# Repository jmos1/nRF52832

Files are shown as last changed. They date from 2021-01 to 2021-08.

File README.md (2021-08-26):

# nRF52832 Demo Board
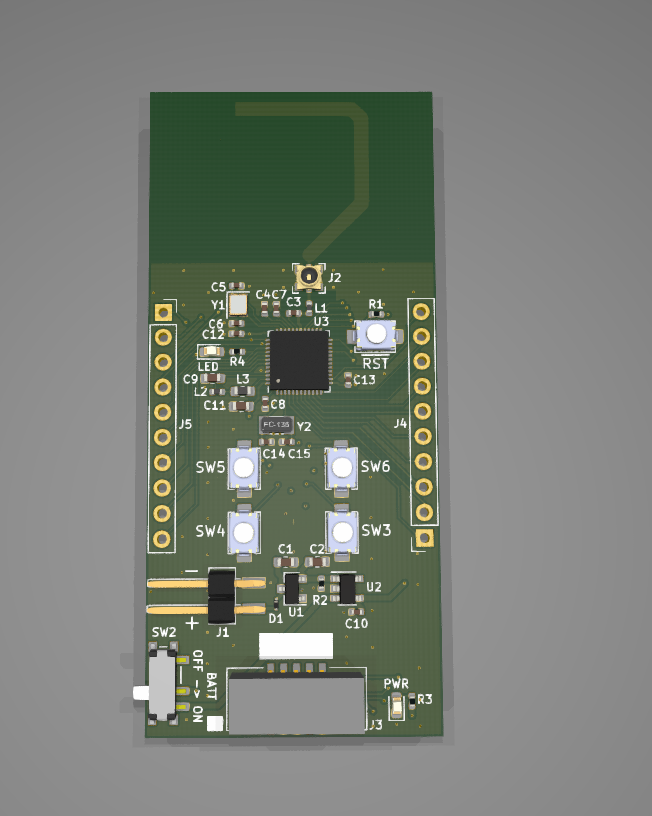
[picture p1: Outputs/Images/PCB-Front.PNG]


### Summary: ###
  4 layer PCB based on Nordic's nRF52832 BLE chip. The antenna needs to be tuned with an exacto knife until
  the VSWR is as close to 1 at 2.4GHz - 2.45GHz as possible. The code to demonstrate that the antenna works 
  as well as the buttons and LEDs will be released when I catch a break from grad school.

  The BOM, schematic PDF, and gerber files are all accessible in the _'Outputs/'_ folder. 
  Other project files are not included because they add clutter and can be generated from the project itself in KiCad.
  Thanks.
  
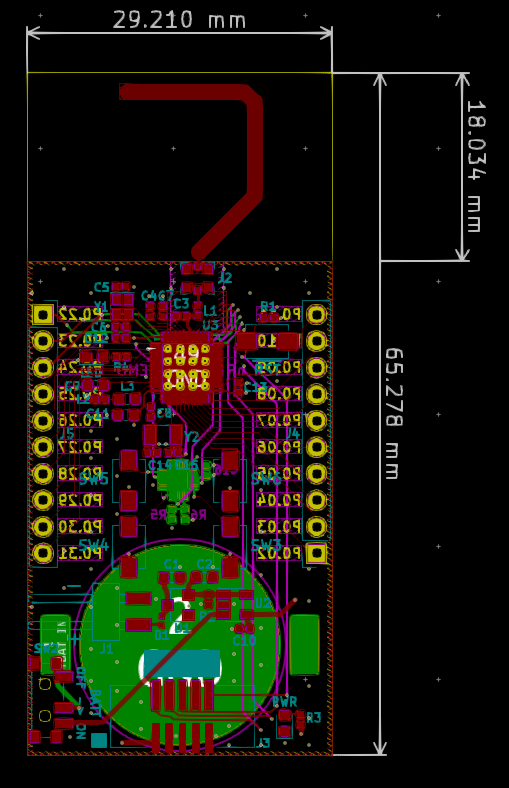
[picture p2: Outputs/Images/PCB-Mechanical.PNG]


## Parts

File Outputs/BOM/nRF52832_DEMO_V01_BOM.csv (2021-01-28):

Reference | Quantity | Value | Description | Manufacturer | MPN | Supplier
BT1 | 1 | CR2032 CLIP | nRF52832_DEMO_V01:BC-2003-G-TR | MPD | BC-2003-G-TR | DigiKey
C11 | 1 | 4u7, 25V | Capacitor_SMD:C_0603_1608Metric | Murata Electronics | GRM188R61E475KE11D | DigiKey
C3 | 1 | 0p8, 100V | Capacitor_SMD:C_0402_1005Metric | Murata Electronics | GRM1555C2AR80BA01D | DigiKey
C4 | 1 | 100p, 25V | Capacitor_SMD:C_0402_1005Metric | Murata Electronics | GRM1555C1E101JA01D | DigiKey
C6 C5 C14 C15 | 4 | 12p, 25V | Capacitor_SMD:C_0402_1005Metric | Murata Electronics | GRM1555C1E120JA01D | DigiKey
C7 | 1 | NC | Capacitor_SMD:C_0402_1005Metric | X | X | DigiKey
C8 C12 C13 C10 C16 | 5 | 100n, 25V | Capacitor_SMD:C_0402_1005Metric | Murata Electronics | GRM155R71E104KE14J | DigiKey
C9 C2 C1 | 3 | 1u, 25V | Capacitor_SMD:C_0603_1608Metric | Murata Electronics | GCM188R71E105KA64D | DigiKey
D1 | 1 | NSR0620P2T5G | nRF52832_DEMO_V01:NSR0620P2T5G | ON Semiconductor | NSR0620P2T5G | DigiKey
D3 D2 | 2 | GRN | LED_SMD:LED_0603_1608Metric | OSRAM Opto Semiconductors Inc. | LG L29K-F2J1-24-Z | DigiKey
J1 | 1 | M20-8890245 | nRF52832_DEMO_V01:M20-8890245 | Harwin Inc. | M20-8890245 | DigiKey
J2 | 1 | MM8130-2600RB8 | nRF52832_DEMO_V01:MM8130-2600RB8 | Murata Electronics | MM8130-2600RB8 | DigiKey
J3 | 1 | 3221-10-0300-00 | nRF52832_DEMO_V01:3221-10-0300-00 | CNC Tech | 3221-10-0300-00-TR | DigiKey
J5 J4 | 2 | Conn_01x10_Male | Connector_PinSocket_2.54mm:PinSocket_1x10_P2.54mm_Vertical | X | X | DigiKey
L1 | 1 | 3n9 | Inductor_SMD:L_0402_1005Metric | Murata Electronics | LQP15MN3N9B02D | DigiKey
L2 | 1 | 15n | Inductor_SMD:L_0402_1005Metric | Taiyo Yuden | HK100515NJ-T | DigiKey
L3 | 1 | 10u | Inductor_SMD:L_0603_1608Metric | Taiyo Yuden | LBMF1608T100K | DigiKey
R1 R2 | 2 | 10KR | Resistor_SMD:R_0402_1005Metric | Vishay Beyschlag | MCS04020C1002FE000 | DigiKey
R4 R3 | 2 | 560R | Resistor_SMD:R_0402_1005Metric | Panasonic Electronic Components | ERJ-2RKF5600X | DigiKey
R5 | 1 | NC | Resistor_SMD:R_0402_1005Metric | X | X | DigiKey
R6 | 1 | 100KR | Resistor_SMD:R_0402_1005Metric | Vishay Beyschlag | MCS04020C1003FE000 | DigiKey
SW2 | 1 | CUS-12TB | nRF52832_DEMO_V01:CUS-12TB | Nidec Copal Electronics | CUS-12TB | DigiKey
SW4 SW3 SW1 SW5 SW6 | 5 | SW_Push | nRF52832_DEMO_V01:Pushbutton_Generic | E-Switch | TL1015AF160QG | DigiKey
U1 | 1 | AP7333-33SRG-7 | Package_TO_SOT_SMD:SOT-23 | Diodes Incorporated | AP7333-33SAG-7 | DigiKey
U2 | 1 | TPS2105DBVR | Package_TO_SOT_SMD:SOT-23-5 | Texas Instruments | TPS2105DBVR | DigiKey
U3 | 1 | nRF52832-QFxx | Package_DFN_QFN:QFN-48-1EP_6x6mm_P0.4mm_EP4.6x4.6mm_ThermalVias | Nordic Semiconductor | NRF52832-QFAA-R | DigiKey
U4 | 1 | NX3DV2567 | Package_DFN_QFN:QFN-16-1EP_3x3mm_P0.5mm_EP1.75x1.75mm | NXP USA Inc. | NX3DV2567HR,115 | DigiKey
Y1 | 1 | Q22FA12800025 | Crystal:Crystal_SMD_2016-4Pin_2.0x1.6mm | EPSON | FA-128 32.0000MF10Z-AJ3 | DigiKey
Y2 | 1 | FC-135R 32.7680KA-AC3 | Crystal:Crystal_SMD_3215-2Pin_3.2x1.5mm | EPSON | FC-135R 32.7680KA-AC3 | DigiKey

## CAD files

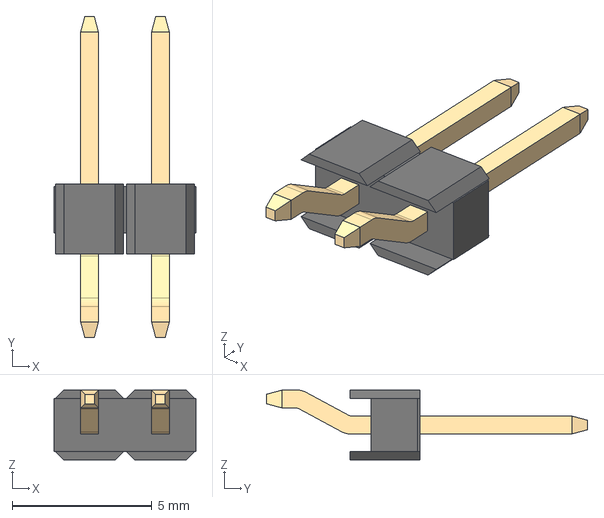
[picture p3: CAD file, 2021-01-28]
3D Models/HDR_2x2_Male_m20-8890245_asm.stp
5.08 x 11.5 x 2.50 mm
M20-88902_MOULD
M20-889_CONTACT x 2

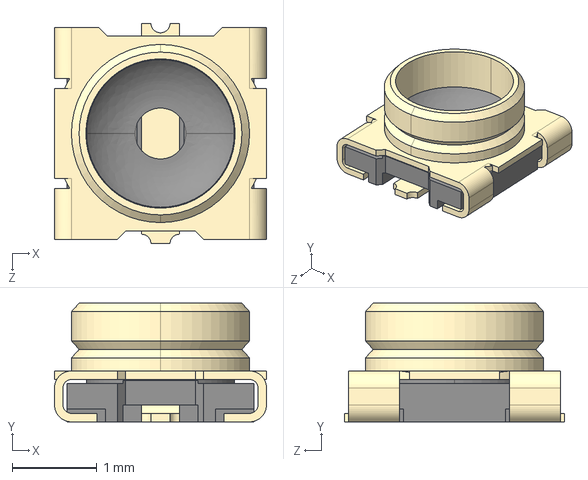
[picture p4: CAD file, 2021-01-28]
3D Models/SWF_MM8130-2600RA2.STEP
2.50 x 1.40 x 2.60 mm

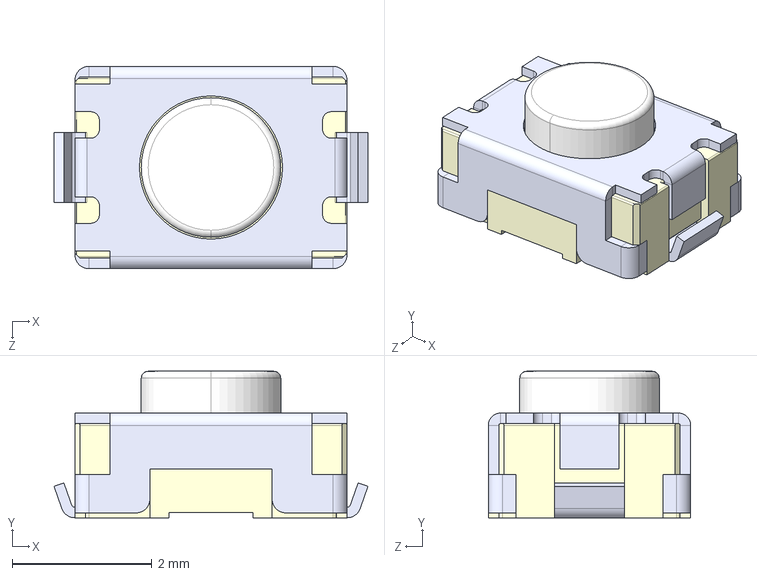
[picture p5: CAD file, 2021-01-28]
3D Models/SW_TL1015AF160QG.STEP
4.50 x 2.10 x 2.90 mm

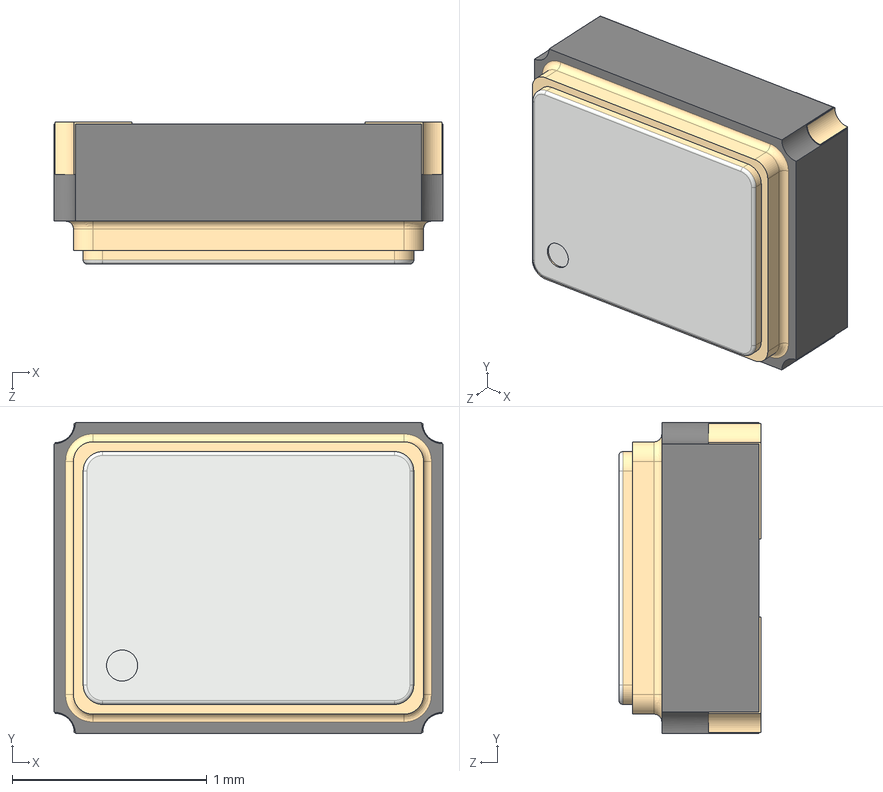
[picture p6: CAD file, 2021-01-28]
3D Models/XTAL_32MHz_FA-128 32.0000MF10Z-AJ3.step
2.00 x 1.60 x 0.73 mm

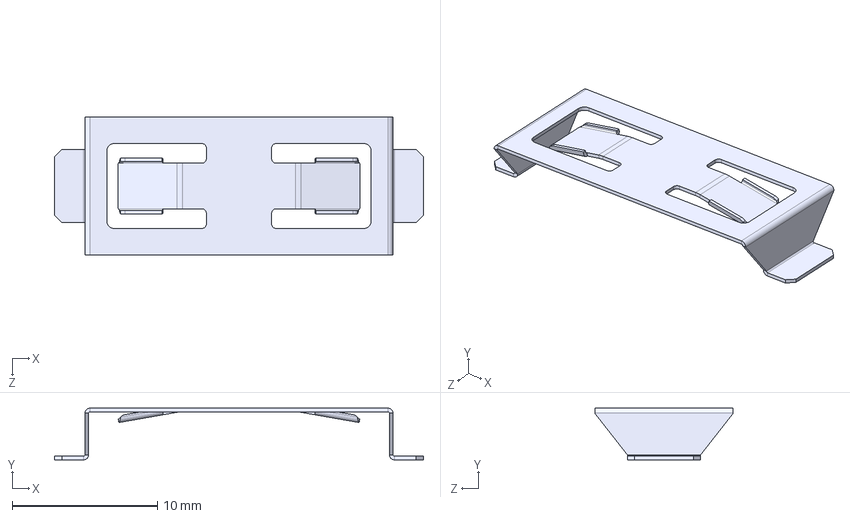
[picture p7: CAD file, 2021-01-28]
3D Models/BATT_CLIP_BC-2003.STEP
25.4 x 3.56 x 9.53 mm

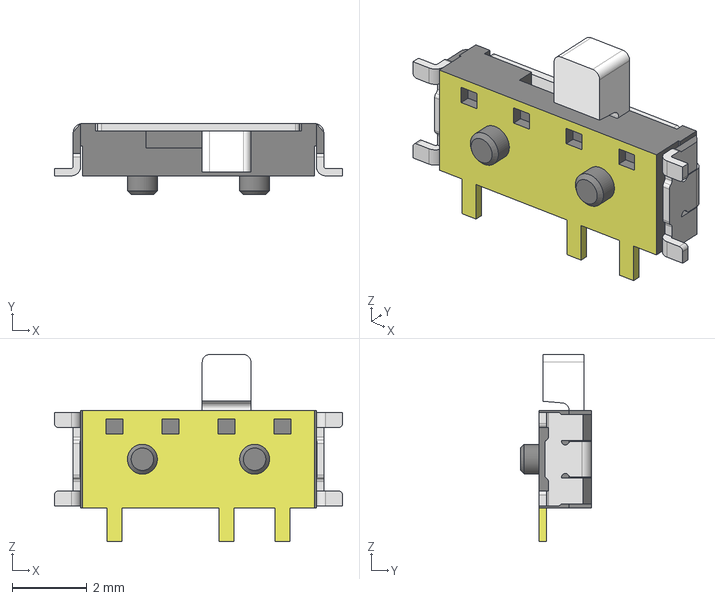
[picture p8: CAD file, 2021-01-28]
3D Models/CUS-12TB.stp
7.70 x 1.90 x 5.00 mm
_CUS-12-body
_CUS-12-slider

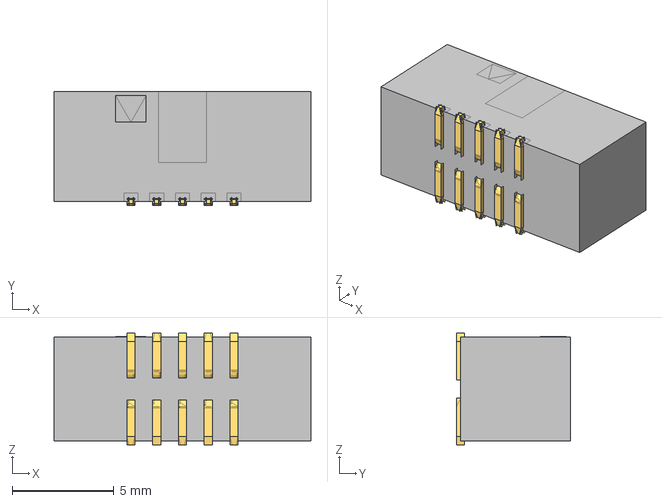
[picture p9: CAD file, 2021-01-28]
3D Models/3220-10-0300.igs
12.7 x 5.60 x 5.50 mm

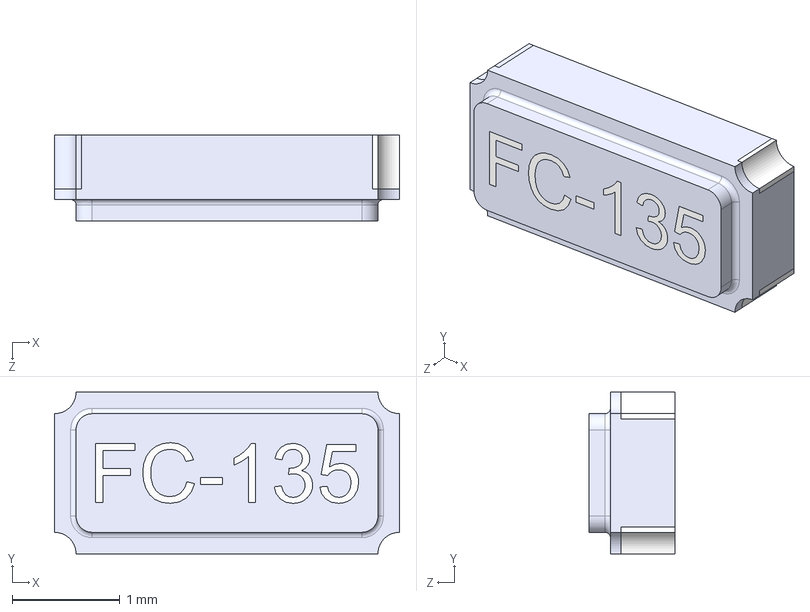
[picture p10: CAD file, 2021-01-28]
3D Models/XTAL_3.2768_FC-135.STEP
3.20 x 1.50 x 0.8 mm
Pin 2
Pin 1
Tekst Inlay

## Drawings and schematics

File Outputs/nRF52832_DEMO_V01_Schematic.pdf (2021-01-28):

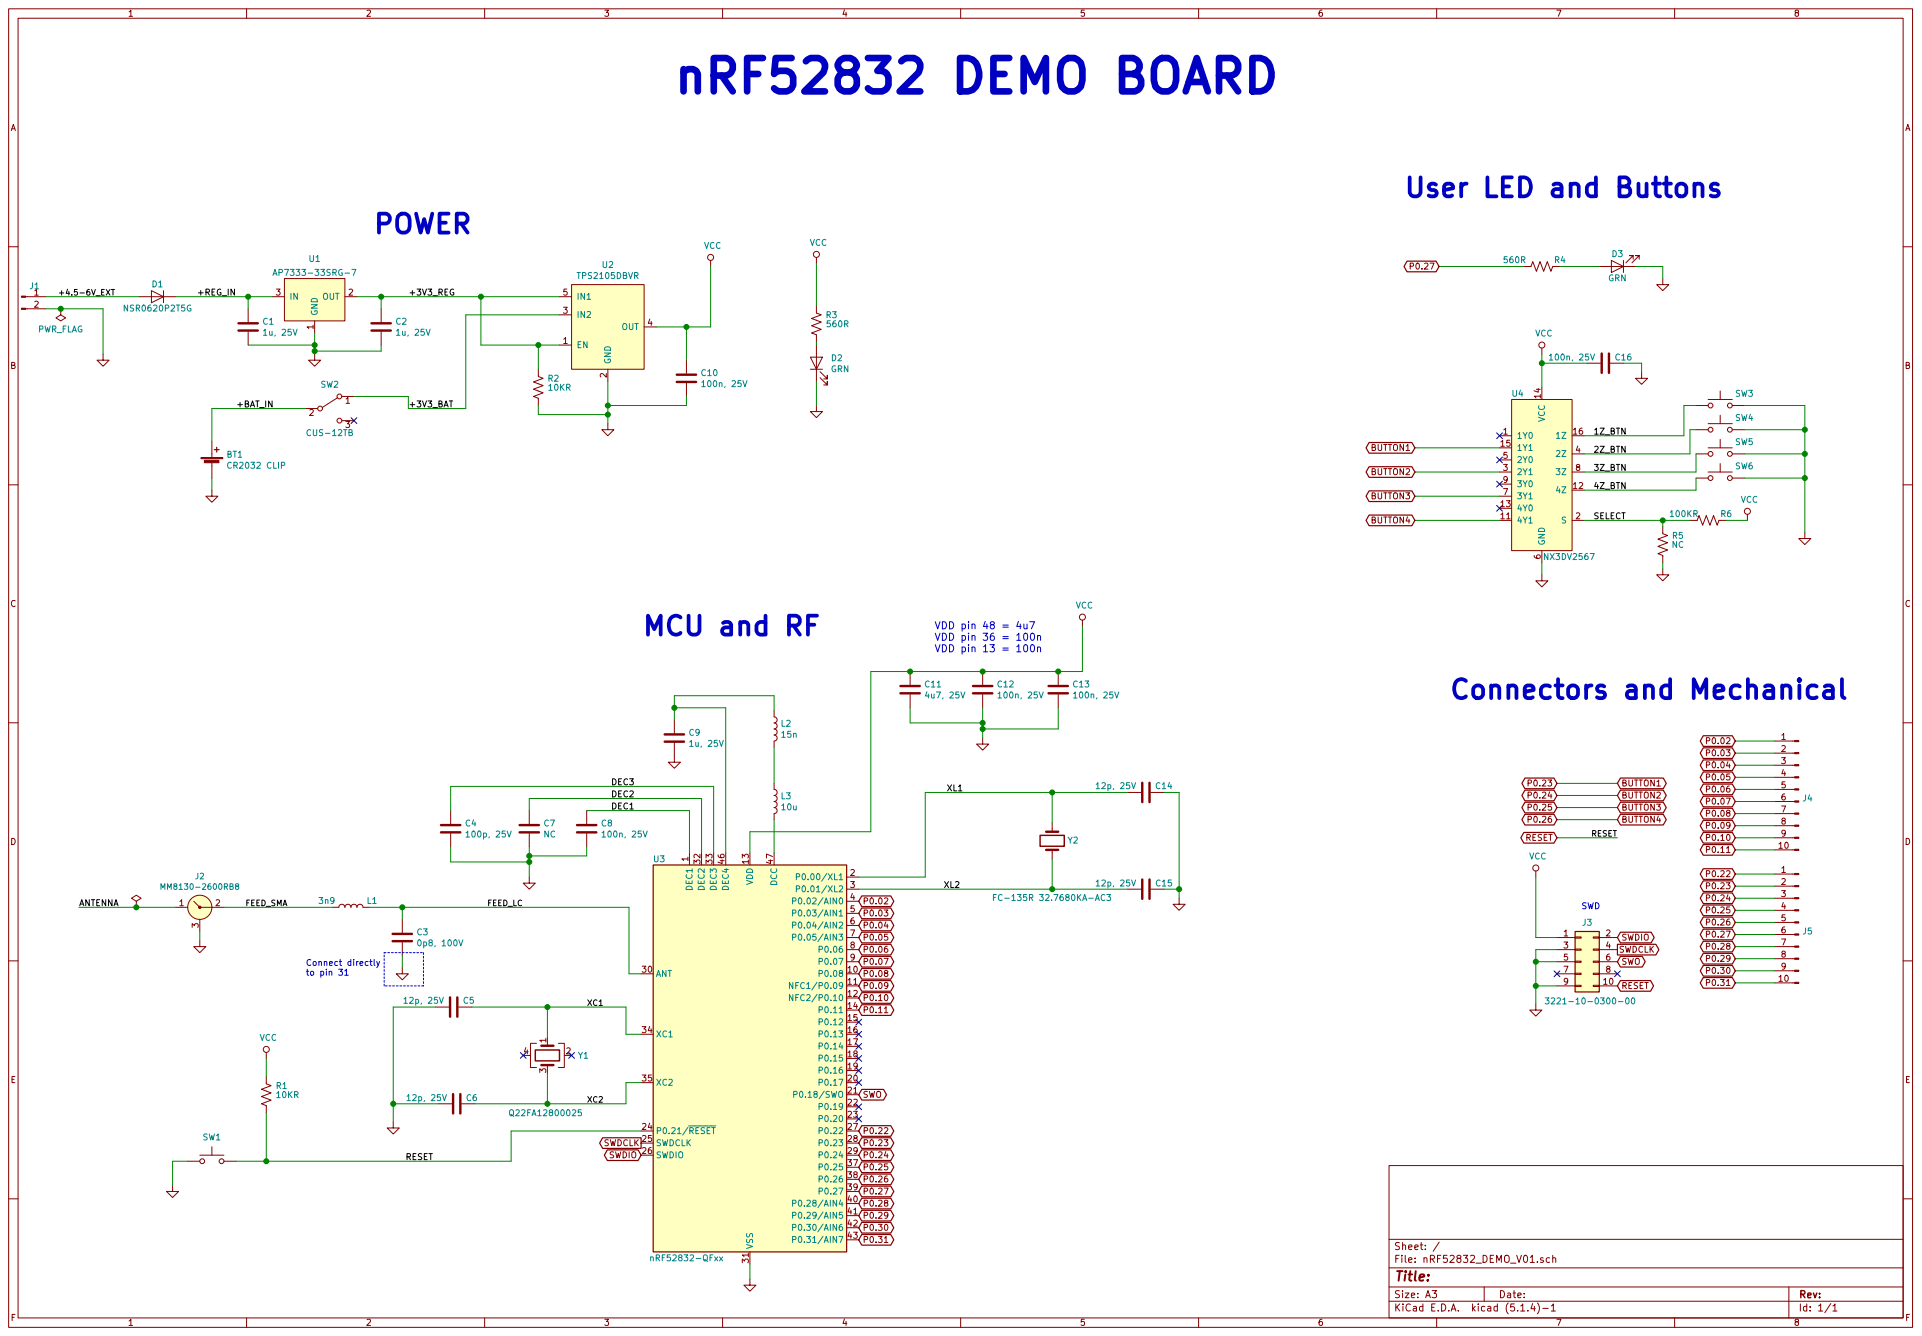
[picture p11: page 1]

User LED and Buttons

1 P0.08 10 NFC1/P0.09 11 NFC2/P0.10 12 VDD 13 P0.11 14 P0.12 15 P0.13 16 P0.14 17 P0.15 18 P0.16 19 P0.00/XL1 2 P0.17 20 P0.18/SWO 21 P0.19 22 P0.20 23 P0.21/RESET 24 SWDCLK 25 SWDIO 26 P0.22 27 P0.23 28 P0.24 29 P0.01/XL2 3 ANT 30 VSS 31 DEC2 32 DEC3 33 XC1 34 XC2 35 P0.25 37 P0.26 38 P0.27 39 P0.02/AIN0 4 P0.28/AIN4 40 P0.29/AIN5 41 P0.30/AIN6 42 P0.31/AIN7 43 DEC4 46 DCC 47 P0.03/AIN1 5 P0.04/AIN2 6 P0.05/AIN3 7 P0.06 8 P0.07 9 U3

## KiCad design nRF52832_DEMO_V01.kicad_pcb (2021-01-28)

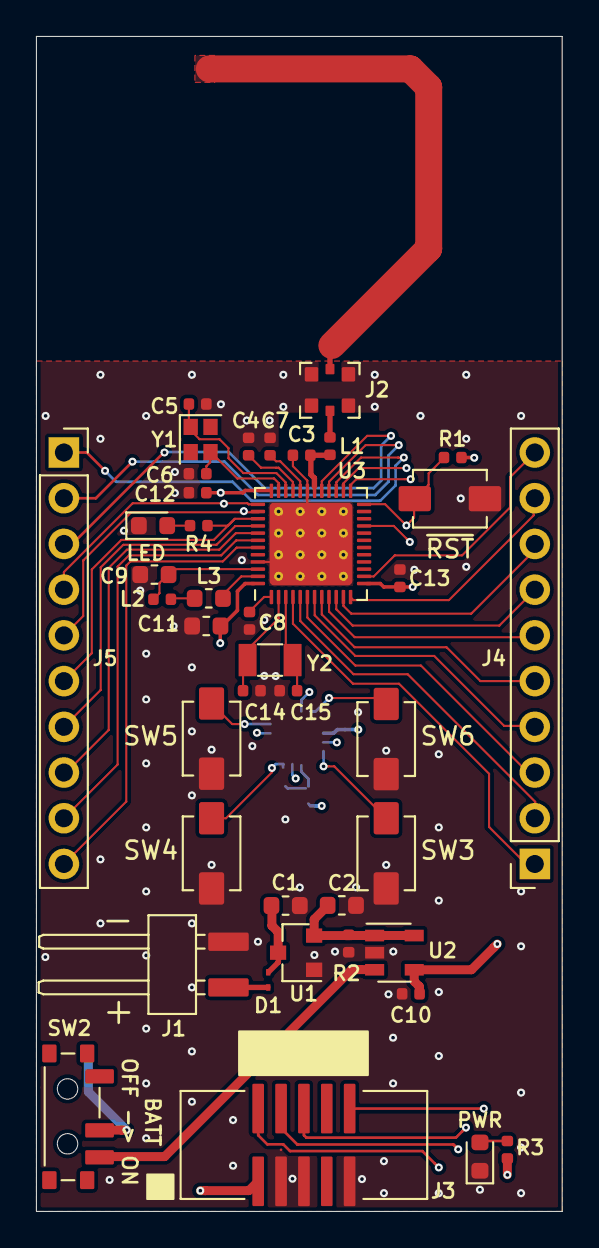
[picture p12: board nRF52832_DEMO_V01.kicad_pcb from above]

Board: 4 copper layers, 29.2 x 65.3 mm, 45 parts (0 on the bottom side), 50 nets.

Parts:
BT1: CR2032 CLIP; BC-2003-G-TR
C1, C2, C9: 1u, 25V; C_0603_1608Metric
C3: 0p8, 100V; C_0402_1005Metric
C4: 100p, 25V; C_0402_1005Metric
C5, C6, C14, C15: 12p, 25V; C_0402_1005Metric
C7: NC; C_0402_1005Metric
C8, C10, C12, C13, C16: 100n, 25V; C_0402_1005Metric
C11: 4u7, 25V; C_0603_1608Metric
D1: NSR0620P2T5G
J1: M20-8890245
J2: MM8130-2600RB8
J3: 3221-10-0300-00
J4, J5: Conn_01x10_Male; PinSocket_1x10_P2.54mm_Vertical
L1: 3n9; L_0402_1005Metric
L2: 15n; L_0402_1005Metric
L3: 10u; L_0603_1608Metric
LED: GRN; LED_0603_1608Metric
PWR: GRN; LED_0603_1608Metric
R1, R2: 10KR; R_0402_1005Metric
R3, R4: 560R; R_0402_1005Metric
R5: NC; R_0402_1005Metric
R6: 100KR; R_0402_1005Metric
SW2: CUS-12TB
SW3, SW4, SW5: SW_Push; Pushbutton_Generic
SW6: TL1015AF160QG; Pushbutton_Generic
U1: AP7333-33SAG-7; SOT-23
U2: TPS2105DBVR; SOT-23-5
U3: nRF52832-QFxx; QFN-48-1EP_6x6mm_P0.4mm_EP4.6x4.6mm_ThermalVias
U4: NX3DV2567; QFN-16-1EP_3x3mm_P0.5mm_EP1.75x1.75mm
Y1: Q22FA12800025; Crystal_SMD_2016-4Pin_2.0x1.6mm
Y2: FC-135R 32.7680KA-AC3; Crystal_SMD_3215-2Pin_3.2x1.5mm

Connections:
/1Z_BTN: SW3.1, U4.16
/2Z_BTN: SW4.1, U4.4
/3Z_BTN: SW5.1, U4.8
/4Z_BTN: SW6.1, U4.12
/+3V3_BAT: SW2.1, U2.3
/+3V3_REG: C2.1, R2.1, U1.2, U2.1, U2.5
/+4.5-6V_EXT: D1.2, J1.1
/+BAT_IN: BT1.1, SW2.2
/+REG_IN: C1.1, D1.1, U1.3
/DEC1: C8.1, U3.1
/DEC2: C7.1, U3.32
/DEC3: C4.1, U3.33
/FEED_LC: C3.1, L1.2, U3.30
/FEED_SMA: J2.2, L1.1
/SELECT: R5.1, R6.1, U4.2
/XC1: C5.2, U3.34, Y1.1
/XC2: C6.1, U3.35, Y1.3
/XL1: C14.1, U3.2, Y2.2
/XL2: C15.2, U3.3, Y2.1
BUTTON1: J5.2, U3.28, U4.15
BUTTON2: J5.3, U3.29, U4.3
BUTTON3: J5.4, U3.37, U4.7
BUTTON4: J5.5, U3.38, U4.11
GND: BT1.2, C1.2, C2.2, C3.2, C4.2, C5.1, C6.2, C7.2, C8.2, C9.2, C10.2, C11.2, C12.2, C13.2, C14.2, C15.1, C16.1, J1.2, J2.3, J3.3, J3.5, J3.9, LED.1, PWR.1, R2.2, R5.2, SW3.2, SW4.2, SW5.2, SW6.2, U1.1, U2.2, U3.31, U3.45, U3.49, U4.6
unnamed: C9.1, L2.1, U3.46
unnamed: PWR.2, R3.2
unnamed: LED.2, R4.2
unnamed: L2.2, L3.1
unnamed: L3.2, U3.47
P0.02: J4.1, U3.4
P0.03: J4.2, U3.5
P0.04: J4.3, U3.6
P0.05: J4.4, U3.7
P0.06: J4.5, U3.8
P0.07: J4.6, U3.9
P0.08: J4.7, U3.10
P0.09: J4.8, U3.11
P0.10: J4.9, U3.12
P0.11: J4.10, U3.14
P0.22: J5.1, U3.27
P0.27: J5.6, R4.1, U3.39
P0.28: J5.7, U3.40
P0.29: J5.8, U3.41
P0.30: J5.9, U3.42
P0.31: J5.10, U3.43
RESET: J3.10, R1.2, U3.24
SWDCLK: J3.4, U3.25
SWDIO: J3.2, U3.26
SWO: J3.6, U3.21
VCC: C10.1, C11.1, C12.1, C13.1, C16.2, J3.1, R1.1, R3.1, R6.2, U2.4, U3.13, U3.36, U3.48, U4.14

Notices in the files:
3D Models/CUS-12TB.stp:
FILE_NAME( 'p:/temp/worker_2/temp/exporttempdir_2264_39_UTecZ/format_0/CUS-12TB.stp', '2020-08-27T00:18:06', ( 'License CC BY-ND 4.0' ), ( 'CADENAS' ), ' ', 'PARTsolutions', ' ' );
